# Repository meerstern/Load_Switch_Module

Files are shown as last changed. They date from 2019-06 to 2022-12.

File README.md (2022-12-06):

# Load_Switch_Module
SiP32431 load switch module 

## 概要 
  * Vishay製超低漏洩電流ロードスイッチ[SiP32431][1]を搭載した変換基板です。
  * 1.5V~5.5V、最⼤1.4Aまでの負荷の電源管理が可能です。  
  * SDカードやセンサ等をマイコンからON/OFF制御する場合に最適です。
  * FETを使⽤する場合に⽐べ、漏れ電流が10pAと非常に⼩さいことが特徴です。
  * EN端⼦がHighの時、VOUTからVIN電源が出⼒されます。  
  * 安定化のため、EN端子は基板上で20kΩでプルダウンしています。  
  * 電池で駆動させるIoT機器ではロードスイッチは欠かせません。  
  
## 販売サイト
  * [スイッチサイエンス][2]
 
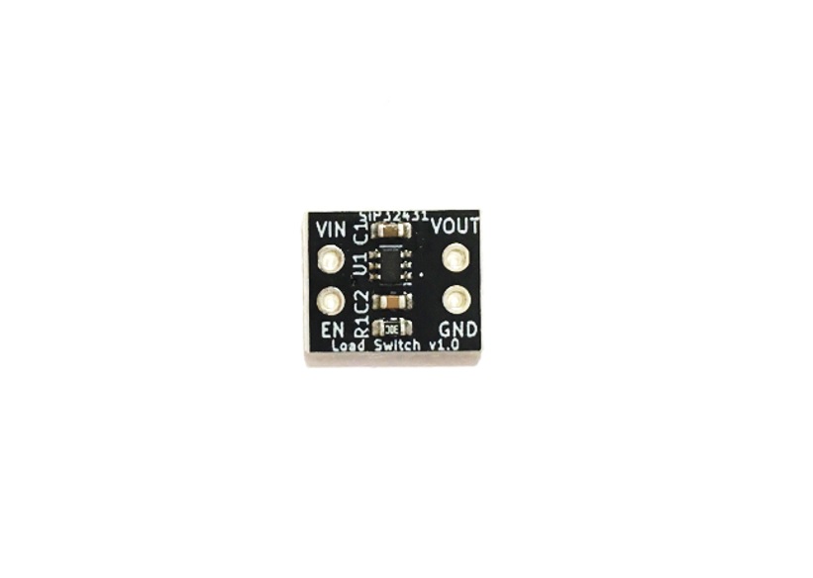
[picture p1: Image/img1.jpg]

   
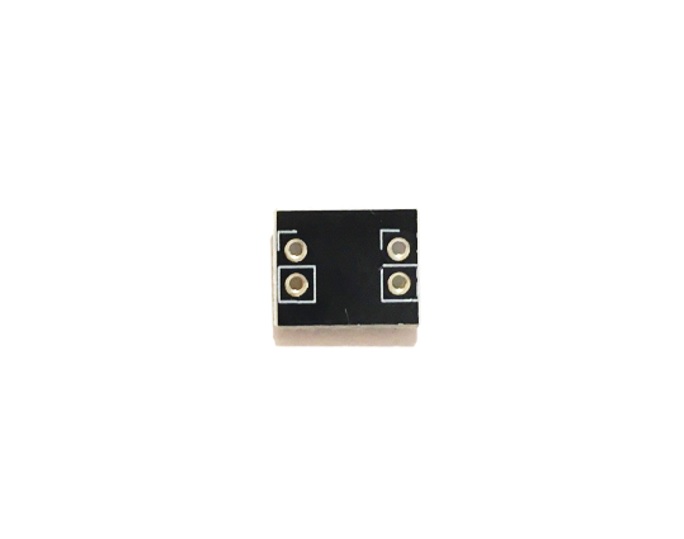
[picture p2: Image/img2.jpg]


[1]: https://www.vishay.com/docs/66597/sip32431.pdf "*1"
[2]: https://www.switch-science.com/products/5796
MIT Lisense

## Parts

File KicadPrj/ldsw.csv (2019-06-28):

Elecrow PN | Parts | Value | Package | QTY | Digikey/Mouser/Manufacturer Part | Remark/ Link
C15849 | C1 | 1u | C_0603_1608Metric | 1
C14663 | C2 | 0.1u | C_0603_1608Metric | 1
C4184 | R1 | 20k | R_0603_1608Metric | 1
 | U1 | LDSW_SiP32431 | SOT-363_SC-70-6 | 1 | 781-SIP32431DR3-GE3

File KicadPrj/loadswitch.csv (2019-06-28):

ID | 参照記号 | パッケージ | 数 | 名称 | Supplier and ref
1 | C1 | C_0603_1608Metric | 1 | 1u
2 | C2 | C_0603_1608Metric | 1 | 0.1u
3 | J1,J2 | PinHeader_1x02_P2.54mm_Vertical | 2 | Conn_01x02
4 | R1 | R_0603_1608Metric | 1 | R
5 | U1 | SOT-363_SC-70-6 | 1 | LDSW_SiP32431

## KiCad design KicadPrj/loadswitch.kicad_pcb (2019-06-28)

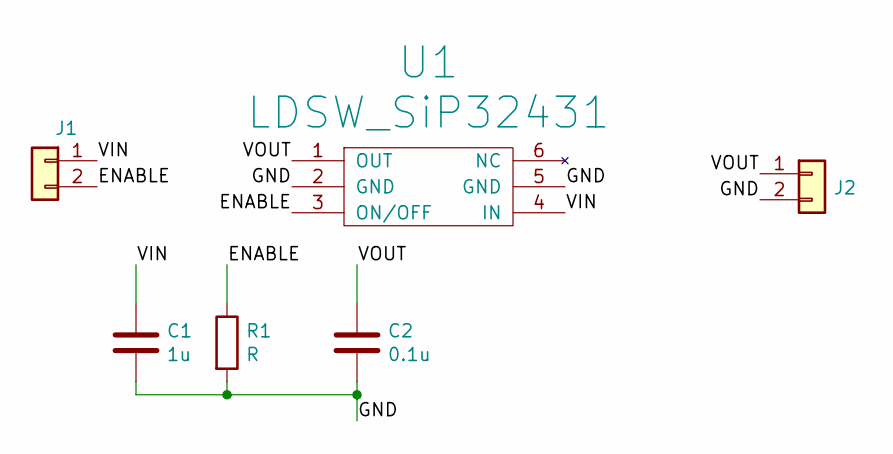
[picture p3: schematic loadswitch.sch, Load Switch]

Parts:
C1: 1u; C_0603_1608Metric
C2: 0.1u; C_0603_1608Metric
J1, J2: Conn_01x02; PinHeader_1x02_P2.54mm_Vertical
R1: R; R_0603_1608Metric
U1: LDSW_SiP32431; SOT-363_SC-70-6

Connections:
/ENABLE: J1.2, R1.1, U1.3 (ON/OFF)
/GND: C1.2, C2.2, J2.2, R1.2, U1.2 (GND), U1.5 (GND)
/VIN: C1.1, J1.1, U1.4 (IN)
/VOUT: C2.1, J2.1, U1.1 (OUT)

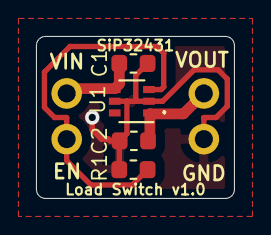
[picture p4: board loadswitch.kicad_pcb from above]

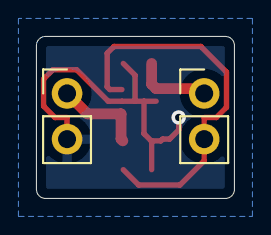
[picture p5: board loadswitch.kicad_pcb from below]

Board: 2 copper layers, 11.0 x 9.0 mm, 6 parts (2 on the bottom side), 4 nets.
